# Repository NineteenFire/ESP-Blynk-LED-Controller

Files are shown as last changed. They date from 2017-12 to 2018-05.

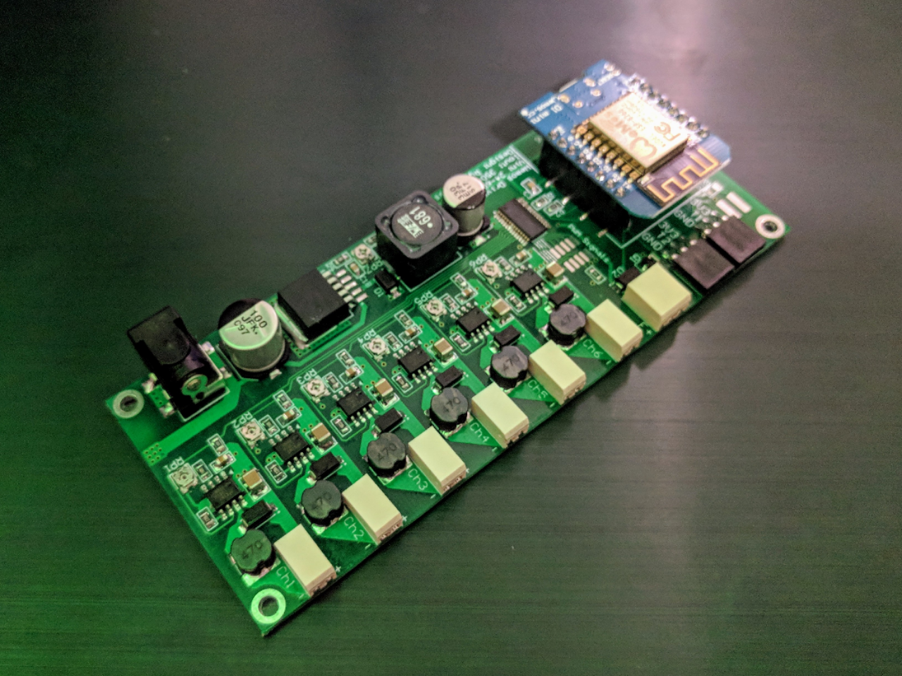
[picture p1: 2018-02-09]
Pictures/Driver PCB.jpg

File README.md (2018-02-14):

# ESP-Blynk-LED-Controller

## Setup after programming ESP:

1. Check your available wifi networks for "LED AP" and connect to it, it should prompt you to select your wifi network and put in your Blynk token (best to copy it to your clipboard before running as there is a 5 minute timeout)
2. Once you've put in that info you should be able to connect via the Blynk app

## Once your Blynk app is connected:

1. Select Sunrise/Sunset, Daylight and Moonlight time period
2. Select "Fan On Temp", this is the temperature setpoint where the fan will be enabled when the heatsink reaches this temperature
3. Select Fade Duration, this is how long the app will take to ramp between light modes (if the ramp overlaps the next start time it will ramp from the current point to the new set values)
4. On setup tab select a test mode, ie "Test MaxPWM" which is your brightest mode
5. Move the sliders to the brightness you want
6. Hit the save button, this will save the current slider values to that mode
7. Repeat steps 4-6 for dim levels and moonlight levels
8. Set mode to normal operation and you should be good to go

## Hardware

### Breadboard wiring diagram:
Breadboard wiring diagram
Parts needed:
- Wemos D1 (or nodeMCU)
- DS18B20
- Adafruit PCA9685
- N-Channel MOSFet to drive fan

### Custom driver PCB
Custom driver PCB

## Libraries

- [Adafruit PWM Servo Driver](https://github.com/adafruit/Adafruit-PWM-Servo-Driver-Library)
- [Arduino JSON](https://arduinojson.org/doc/installation/)
- [Arduino OTA](https://github.com/esp8266/Arduino/tree/master/libraries/ArduinoOTA)
- [Blynk](https://github.com/blynkkk/blynk-library)
- [Dallas Temperature](https://github.com/milesburton/Arduino-Temperature-Control-Library)
- [Simple Timer](https://github.com/marcelloromani/Arduino-SimpleTimer/tree/master/SimpleTimer)
- [Time Library](https://github.com/PaulStoffregen/Time)
- [Wifi Manager](https://github.com/tzapu/WiFiManager)

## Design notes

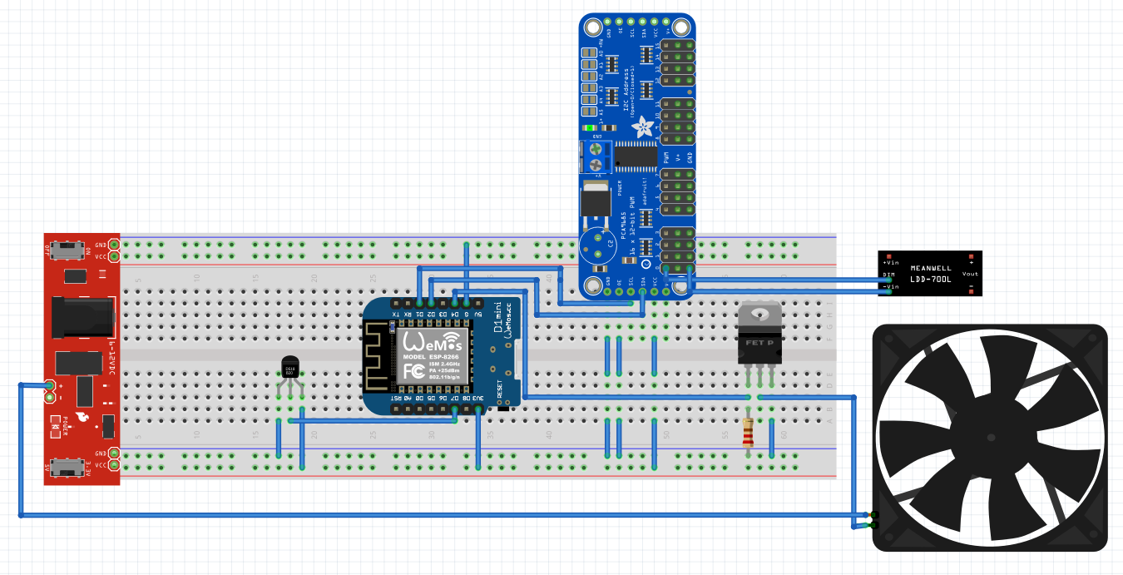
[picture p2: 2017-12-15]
Pictures/Connections.png

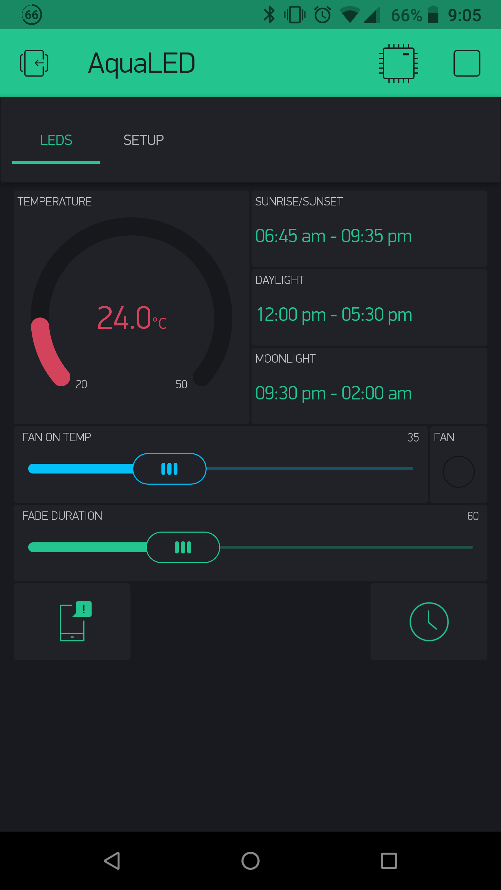
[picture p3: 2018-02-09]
Pictures/Blynk - Main screen.png

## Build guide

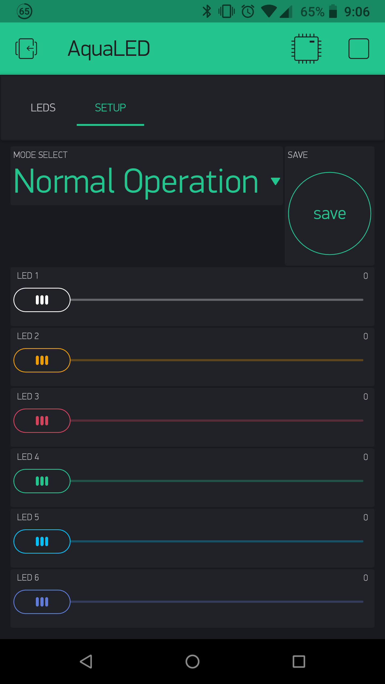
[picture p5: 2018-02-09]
Pictures/Blynk - Setup screen.png

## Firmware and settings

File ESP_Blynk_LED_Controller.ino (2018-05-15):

//#define BLYNK_PRINT Serial    // Comment this out to disable prints and save space

#include <FS.h>                   // https://github.com/tzapu/WiFiManager This Library needs to be included FIRST!
#include <BlynkSimpleEsp8266.h>
#include <ArduinoOTA.h>
#include <TimeLib.h>
#include <WidgetRTC.h>
#include <Wire.h>
#include <Adafruit_PWMServoDriver.h>
#include <OneWire.h> // network library to communicate with the DallasTemperature sensor, 
#include <DallasTemperature.h>  // library for the Temp sensor itself
//included libraries for WiFiManager - AutoConnectWithFSParameters
#include <DNSServer.h>
#include <ESP8266WebServer.h>
#include <WiFiManager.h>          //https://github.com/tzapu/WiFiManager
#include <ArduinoJson.h>          //https://github.com/bblanchon/ArduinoJson
#include <EEPROM.h>

void updateBlynkSliders(boolean updateAll=true);

byte pSDA=4;
byte pSCL=5;
byte pEnFAN=16;
byte pFANPWM=0;
byte pOneWire=13;
byte pOnBoardLED=2;

// WiFiManager
char blynk_token[34] = "BLYNK_TOKEN";//added from WiFiManager - AutoConnectWithFSParameters
//flag for saving data
bool shouldSaveConfig = false;
//callback notifying the need to save config
void saveConfigCallback () {
  BLYNK_LOG("Should save config");
  shouldSaveConfig = true;
}

bool isFirstConnect = true;
bool smartStartupRun = false;
bool appConnected = false;

char Time[16];

unsigned long startsecond = 0;        // time for LEDs to ramp to full brightness
unsigned long stopsecond = 0;         // finish time for LEDs to ramp to dim level from full brightness
unsigned long sunriseSecond = 0;      // time for LEDs to start ramping to dim level
unsigned long sunsetSecond = 0;       // finish time for LEDs to dim off
unsigned long moonStartSecond = 0;      // time for LEDs to start ramping to moonlight level
unsigned long moonStopSecond = 0;       // time for LEDs to ramp off
unsigned long nowseconds = 0;         // time  now  in seconds

//0=not ramping, 3=moon->dim, 4=dim->max, 5=max->dim, 6=dim->moon
unsigned int fadeInProgress = 0;
unsigned long fadeStartTimeMillis = 0;
unsigned long fadeStartTimeSeconds = 0;
unsigned long fadeTimeSeconds = 0;
unsigned long fadeTimeMillis = 0;

struct LEDCh // for storing light intensity values
{
  unsigned int fadeIncrementTime;
  unsigned int currentPWM;
  unsigned int lastPWM;
  unsigned int targetPWM;
  unsigned int maxPWM;
  unsigned int dimPWM;
  unsigned int tempPWM;
  unsigned int moonPWM;
};
typedef struct LEDCh channel;
const int numCh = 6;
channel LEDsettings[numCh];

int LEDMode = 1; //1=operating, 2=Configure MaxPWM, 3=Configure dimPWM, 4=Configure moonPWM

// Data wire is plugged into port 2 on the Wemos
#define ONE_WIRE_BUS D7

// Setup a oneWire instance to communicate with any OneWire devices (not just Maxim/Dallas temperature ICs)
OneWire oneWire(ONE_WIRE_BUS);

// Pass our oneWire reference to Dallas Temperature. 
DallasTemperature sensors(&oneWire);

// array to hold device addresses (can increase array length if using more sensors)
DeviceAddress tempSensors[3];
int numTempSensors;
int fanOnTemp = 0;

WidgetRTC rtc;
WidgetLED fanLED(V14);
BlynkTimer timer;
Adafruit_PWMServoDriver pwm = Adafruit_PWMServoDriver();

void setup()
{
  Wire.begin(pSDA,pSCL);
  //Wire.setClock(400000L);
  ArduinoOTA.begin();
  Serial.begin(115200);
  
  pinMode(pOnBoardLED, OUTPUT);
  pinMode(pFANPWM, OUTPUT);
  pinMode(pEnFAN, OUTPUT);
  digitalWrite(pOnBoardLED, LOW);
  digitalWrite(pFANPWM, LOW);
  digitalWrite(pEnFAN, LOW);
  
  pwm.begin();
  pwm.setPWMFreq(250);

  //Start dallas temperature temp sensors
  sensors.begin();
  // locate devices on the bus
  numTempSensors = sensors.getDeviceCount();
  BLYNK_LOG("Found %d temperature sensors.",numTempSensors);
  for( int i = 0 ; i < numTempSensors ; i++)
  {
    if (!sensors.getAddress(tempSensors[i], i))
    {
      BLYNK_LOG("Unable to find address for Device %d",i);
    }
  }

  //The following code is borrowed from WiFiManager
  //clean FS, for testing
  //SPIFFS.format();

  //read configuration from FS json
  BLYNK_LOG("Mounting FS...");

  if (SPIFFS.begin()) {
    BLYNK_LOG("Mounted file system");
    if (SPIFFS.exists("/config.json")) {
      //file exists, reading and loading
      BLYNK_LOG("Config file exists");
      File configFile = SPIFFS.open("/config.json", "r");
      if (configFile) {
        BLYNK_LOG("Opened config file");
        size_t size = configFile.size();
        // Allocate a buffer to store contents of the file.
        std::unique_ptr<char[]> buf(new char[size]);

        configFile.readBytes(buf.get(), size);
        DynamicJsonBuffer jsonBuffer;
        JsonObject& json = jsonBuffer.parseObject(buf.get());
        json.printTo(Serial);
        if (json.success()) {
          BLYNK_LOG("Parsed json");
          strcpy(blynk_token, json["blynk_token"]);
          BLYNK_LOG("Blynk Token in memory: %s",blynk_token);
        } else {
          BLYNK_LOG("Failed to load json config");
        }
      }
    }else{
      BLYNK_LOG("File config.json does not exist",blynk_token);
    }
  } else {
    BLYNK_LOG("Failed to mount FS");
  }
  //end read
  
  // The extra parameters to be configured (can be either global or just in the setup)
  // After connecting, parameter.getValue() will get you the configured value
  // id/name placeholder/prompt default length
  WiFiManagerParameter custom_blynk_token("blynk", "blynk token", blynk_token, 34);
  
  // WiFiManager
  // Local intialization. Once its business is done, there is no need to keep it around
  WiFiManager wifiManager;

  // Set config save notify callback
  wifiManager.setSaveConfigCallback(saveConfigCallback);

  // Add blynk parameter here
  wifiManager.addParameter(&custom_blynk_token);

  // Reset settings - for testing
  //wifiManager.resetSettings();

  //set minimu quality of signal so it ignores AP's under that quality (default: 8%)
  wifiManager.setMinimumSignalQuality();

  // Sets timeout until configuration portal gets turned off
  // useful to make it all retry or go to sleep
  //wifiManager.setTimeout(120);

  //fetches ssid and pass and tries to connect
  //if it does not connect it starts an access point with the specified name
  //and goes into a blocking loop awaiting configuration
  if (!wifiManager.autoConnect("LED AP")) {
    //Serial.println("failed to connect and hit timeout");
    BLYNK_LOG("Failed to connect and hit timeout");
    delay(3000);
    //reset and try again, or maybe put it to deep sleep
    ESP.reset();
    delay(1000);
  }

  //if you get here you have connected to the WiFi
  BLYNK_LOG("LED Controller connected :)");

  //read updated parameters
  strcpy(blynk_token, custom_blynk_token.getValue());

  //save the custom parameters to FS
  if (shouldSaveConfig) {
    BLYNK_LOG("Saving config");
    DynamicJsonBuffer jsonBuffer;
    JsonObject& json = jsonBuffer.createObject();
    json["blynk_token"] = blynk_token;

    File configFile = SPIFFS.open("/config.json", "w");
    if (!configFile) {
      BLYNK_LOG("failed to open config file for writing");
    }

    json.printTo(Serial);
    json.printTo(configFile);
    configFile.close();
    //end save
  }

  setSyncInterval(1000); //make sure time syncs right away
  Blynk.config(blynk_token);
  while (Blynk.connect() == false)
  {
    // Wait until connected, need to handle case where wifi connects but blynk auth invalid...
    
    if((shouldSaveConfig == false)&&(blynk_token == "BLYNK_TOKEN"))
    {
      //This will erase WiFi settings forcing a new AP where Blynk_token can be entered
      //WiFi.disconnect(true); 
      //ESP.reset();
      //OR
      WiFi.begin("FakeSSID","FakePW");     // Replace current WiFi credentials with fake ones
      delay(1000);
      ESP.restart();
    }
    
  }
  rtc.begin();

  //Can update slider colors here if desired
  //Blynk.setProperty(V0, "color", "#F2FAFF"); // COOL WHITE
  //Blynk.setProperty(V1, "color", "#FFEDE0"); // WARM WHITE
  //Blynk.setProperty(V2, "color", "#FD5635"); // RED
  //Blynk.setProperty(V3, "color", "#BFFFB3"); // LIME
  //Blynk.setProperty(V4, "color", "#2E28FF"); // ROYAL BLUE
  //Blynk.setProperty(V5, "color", "#2ECEFF"); // CYAN
  //Blynk.setProperty(V6, "color", "#FD5635"); // RED
  //Blynk.setProperty(V7, "color", "#BD1313"); // DEEP RED

  //Read LED settings from EEPROM
  if(checkEEPROMPWM() == false)
  {
    //if the EEPROM has not been set previously clear memory
    clearPWMValues();
  }
  readPWMValues();
  
  timer.setInterval(500L, ledFade);           // adjust the led lighting every 500ms
  timer.setInterval(1000L, checkSchedule);    // check every second if fade should start
  timer.setInterval(15000L, checkTemp);       // check heatsink temperature every 15 seconds
  timer.setInterval(60000L, reconnectBlynk);  // check every 60s if still connected to server
  
  digitalWrite(pOnBoardLED, HIGH); //ensure light is OFF
  Blynk.notify("LED Controller ONLINE");
  BLYNK_LOG("End of startup.");
}
void loop()
{
  ArduinoOTA.handle();
  if (Blynk.connected()) {
    Blynk.run();
  }
  timer.run();
}

//===Functions===

void reconnectBlynk() {
  if (!Blynk.connected())
  {
    //Turn onboard LED on to indiciate there is an issue
    digitalWrite(pOnBoardLED, LOW);
    if (Blynk.connect())
    {
      digitalWrite(pOnBoardLED, HIGH);
      BLYNK_LOG("Reconnected");
    }
    else {
      digitalWrite(pOnBoardLED, LOW);
      BLYNK_LOG("Not reconnected");
    }
  }else
  {
    //Turn onboard LED off
    digitalWrite(pOnBoardLED, HIGH);
    clockDisplay();
  }
}

void checkSchedule()        // check if ramping should start
{
  if (year() != 1970) 
  {
    nowseconds = ((hour() * 3600) + (minute() * 60) + second());
    //nowseconds = elapsedSecsToday(now());
    unsigned long timingInfo = startsecond + sunriseSecond + moonStartSecond + fadeTimeSeconds;
    if((smartStartupRun == false)&&(timingInfo != 0))
    {
      smartLEDStartup();
      smartStartupRun = true;
      setSyncInterval(600000); //set time sync to every 10 minutes
    }
  }else
  {
    nowseconds = 86401; //set seconds out of range to avoid un-wanted ramps
  }
  
  int i;
  int difference;
  if((nowseconds == sunriseSecond)&&(fadeInProgress != 4)) //ramp from 0 to sunrise values
  {
    sprintf(Time, "%02d:%02d:%02d", hour() , minute(), second());
    BLYNK_LOG("%s\tStarting sunrise...",Time);
    
    fadeInProgress = 4;
    fadeStartTimeMillis = millis();
    fadeStartTimeSeconds = now();
    for(i = 0; i < numCh; i = i + 1) {
      LEDsettings[i].targetPWM = LEDsettings[i].dimPWM;
      LEDsettings[i].lastPWM = LEDsettings[i].currentPWM;
      if(LEDsettings[i].targetPWM > LEDsettings[i].lastPWM){difference = (LEDsettings[i].targetPWM - LEDsettings[i].lastPWM);}
      if(LEDsettings[i].targetPWM < LEDsettings[i].lastPWM){difference = (LEDsettings[i].lastPWM - LEDsettings[i].targetPWM);}
      LEDsettings[i].fadeIncrementTime = fadeTimeMillis / difference;
    }
  }
  else if((nowseconds == startsecond)&&(fadeInProgress != 5)) //ramp from sunrise to max 
  {
    sprintf(Time, "%02d:%02d:%02d", hour() , minute(), second());
    BLYNK_LOG("%s\tRamping to full brightness...",Time);
    
    fadeInProgress = 5;
    fadeStartTimeMillis = millis();
    fadeStartTimeSeconds = now();
    for (i = 0; i < numCh; i = i + 1) {
      LEDsettings[i].targetPWM = LEDsettings[i].maxPWM;
      LEDsettings[i].lastPWM = LEDsettings[i].currentPWM;
      if(LEDsettings[i].targetPWM > LEDsettings[i].lastPWM){difference = (LEDsettings[i].targetPWM - LEDsettings[i].lastPWM);}
      if(LEDsettings[i].targetPWM < LEDsettings[i].lastPWM){difference = (LEDsettings[i].lastPWM - LEDsettings[i].targetPWM);}
      LEDsettings[i].fadeIncrementTime = fadeTimeMillis / difference;
    }
  }
  else if((nowseconds == stopsecond)&&(fadeInProgress != 6)) //ramp from max to sunset values
  {
    sprintf(Time, "%02d:%02d:%02d", hour() , minute(), second());
    BLYNK_LOG("%s\tStarting sunset...",Time);
    
    fadeInProgress = 6;
    fadeStartTimeMillis = millis();
    fadeStartTimeSeconds = now();
    for (i = 0; i < numCh; i = i + 1) {
      LEDsettings[i].targetPWM = LEDsettings[i].dimPWM;
      LEDsettings[i].lastPWM = LEDsettings[i].currentPWM;
      if(LEDsettings[i].targetPWM > LEDsettings[i].lastPWM){difference = (LEDsettings[i].targetPWM - LEDsettings[i].lastPWM);}
      if(LEDsettings[i].targetPWM < LEDsettings[i].lastPWM){difference = (LEDsettings[i].lastPWM - LEDsettings[i].targetPWM);}
      LEDsettings[i].fadeIncrementTime = fadeTimeMillis / difference;
    }
  }
  else if((nowseconds == sunsetSecond)&&(fadeInProgress != 7)) //ramp from sunset to off
  {
    sprintf(Time, "%02d:%02d:%02d", hour() , minute(), second());
    BLYNK_LOG("%s\tRamping LEDs off...",Time);
    
    fadeInProgress = 7;
    fadeStartTimeMillis = millis();
    fadeStartTimeSeconds = now();
    for (i = 0; i < numCh; i = i + 1) {
      LEDsettings[i].targetPWM = 0;
      LEDsettings[i].lastPWM = LEDsettings[i].currentPWM;
      if(LEDsettings[i].targetPWM > LEDsettings[i].lastPWM){difference = (LEDsettings[i].targetPWM - LEDsettings[i].lastPWM);}
      if(LEDsettings[i].targetPWM < LEDsettings[i].lastPWM){difference = (LEDsettings[i].lastPWM - LEDsettings[i].targetPWM);}
      LEDsettings[i].fadeIncrementTime = fadeTimeMillis / difference;
    }
  }
  else if((nowseconds == moonStartSecond)&&(fadeInProgress != 8)) //ramp from off to moon
  {
    sprintf(Time, "%02d:%02d:%02d", hour() , minute(), second());
    BLYNK_LOG("%s\tRamping LEDs to moonlight...",Time);
    
    fadeInProgress = 8;
    fadeStartTimeMillis = millis();
    fadeStartTimeSeconds = now();
    for (i = 0; i < numCh; i = i + 1) {
      LEDsettings[i].targetPWM = LEDsettings[i].moonPWM;
      LEDsettings[i].lastPWM = LEDsettings[i].currentPWM;
      if(LEDsettings[i].targetPWM > LEDsettings[i].lastPWM){difference = (LEDsettings[i].targetPWM - LEDsettings[i].lastPWM);}
      if(LEDsettings[i].targetPWM < LEDsettings[i].lastPWM){difference = (LEDsettings[i].lastPWM - LEDsettings[i].targetPWM);}
      LEDsettings[i].fadeIncrementTime = fadeTimeMillis / difference;
    }
  }
  else if((nowseconds == moonStopSecond)&&(fadeInProgress != 9)) //ramp off from moon
  {
    sprintf(Time, "%02d:%02d:%02d", hour() , minute(), second());
    BLYNK_LOG("%s\tRamping LEDs to moonlight...",Time);
    
    fadeInProgress = 9;
    fadeStartTimeMillis = millis();
    fadeStartTimeSeconds = now();
    for (i = 0; i < numCh; i = i + 1) {
      LEDsettings[i].targetPWM = 0;
      LEDsettings[i].lastPWM = LEDsettings[i].currentPWM;
      if(LEDsettings[i].targetPWM > LEDsettings[i].lastPWM){difference = (LEDsettings[i].targetPWM - LEDsettings[i].lastPWM);}
      if(LEDsettings[i].targetPWM < LEDsettings[i].lastPWM){difference = (LEDsettings[i].lastPWM - LEDsettings[i].targetPWM);}
      LEDsettings[i].fadeIncrementTime = fadeTimeMillis / difference;
    }
  }
  if(appConnected)
  {
    //if we're in normal mode and ramping keep the sliders updated
    if((LEDMode == 1)&&(fadeInProgress != 0))
    {
      //only update one slider per second to reduce traffic
      updateBlynkSliders(false);
    }
  }
}

void ledFade()
{
  int i;
  if(fadeInProgress != 0)
  {
    unsigned long timeElapsed = millis() - fadeStartTimeMillis; //time since the start of fade
    for (i = 0; i < numCh; i = i + 1)
    {
      if(LEDsettings[i].currentPWM != LEDsettings[i].targetPWM)
      {
        //if adjustments are necessary
        if(LEDsettings[i].lastPWM < LEDsettings[i].targetPWM)
        {
          //value increasing
          LEDsettings[i].currentPWM = LEDsettings[i].lastPWM + (timeElapsed / LEDsettings[i].fadeIncrementTime);
        }
        if(LEDsettings[i].lastPWM > LEDsettings[i].targetPWM)
        {
          //value decreasing
          LEDsettings[i].currentPWM = LEDsettings[i].lastPWM - (timeElapsed / LEDsettings[i].fadeIncrementTime);
        }
        //if target == last set to target
        if(LEDsettings[i].lastPWM == LEDsettings[i].targetPWM)
        {
          LEDsettings[i].currentPWM = LEDsettings[i].targetPWM;
        }
      }
      LEDsettings[i].currentPWM = constrain(LEDsettings[i].currentPWM,0,4095);
    }
    if(now() > (fadeStartTimeSeconds + fadeTimeSeconds))
    {
      fadeInProgress = 0;
      for (i = 0; i < numCh; i = i + 1) {
        LEDsettings[i].currentPWM = LEDsettings[i].targetPWM;
      }
    }
    if(LEDMode==1)
    {
      writeLEDs();
    }
  }
}

void writeLEDs() {
  int i;
  for (i = 0; i < numCh; i = i + 1) {
    pwm.setPWM(i,0,LEDsettings[i].currentPWM);
  }
}

void checkTemp()
{
  //read all sensors and keep track of maximum temperature
  sensors.requestTemperatures();
  float temperature[numTempSensors];
  float maxTemperature = 0.0;
  int i = 0;
  for(i = 0 ; i < numTempSensors ; i++)
  {
    temperature[i] = sensors.getTempC(tempSensors[i]);
    if(temperature[i] > maxTemperature)maxTemperature=temperature[i];
  }
  
  //write the maximum temperature to Blynk
  Blynk.virtualWrite(V20, maxTemperature);
  
  //if higher than fan set temperature then turn fan on
  int intTemp = maxTemperature; //temp as integer
  if(intTemp > fanOnTemp)
  {
    //Calculate PWM by temp over fanOnTemp, at 0C above run at 10%, 20C above 100%
    int fanPWM = intTemp - fanOnTemp;
    fanPWM = constrain(fanPWM,0,20);
    fanPWM = map(fanPWM,0,20,10,1023);
    analogWrite(pFANPWM,fanPWM);
    //turn fan on
    digitalWrite(pEnFAN,HIGH);
    fanLED.on();
  }
  if(intTemp < (fanOnTemp-2))
  {
    //turn fan off
    digitalWrite(pEnFAN,LOW);
    analogWrite(pFANPWM,0);
    fanLED.off();
  }
}
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

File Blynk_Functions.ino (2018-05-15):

// This function will run every time Blynk connection is established
BLYNK_CONNECTED() 
{
  if (isFirstConnect)
  {
    Blynk.syncVirtual(V12);//check fade time before schedule
    Blynk.syncVirtual(V10,V11,V13,V22); //Read start/stop/sunrise/sunset times, fan on temp
    Blynk.virtualWrite(V15,1);
    isFirstConnect = false;
    Blynk.run();
  }
}
// This is called when Smartphone App is opened
BLYNK_APP_CONNECTED() {
  BLYNK_LOG("App Connected");
  appConnected = true;
  if(LEDMode == 1)updateBlynkSliders();
}
// This is called when Smartphone App is closed
BLYNK_APP_DISCONNECTED() {
  BLYNK_LOG("App Disconnected");
  appConnected = false;
}
BLYNK_WRITE(V0) {// slider widget to set the maximum led level from the Blynk App.
  int value;// = param.asInt();
  float valueF = param.asFloat();
  valueF = valueF * 40.95;
  value = valueF;
  value = constrain(value,0,4095);
  //if in mode 1 or 2 take new value as currentPWM and set LED to that value for viewing purposes
  if((LEDMode == 2)||(LEDMode == 3)||(LEDMode == 4))
  {
    LEDsettings[0].tempPWM = value;
    pwm.setPWM(0, 0, LEDsettings[0].tempPWM);
    BLYNK_LOG("Setting ch1 current to %d",LEDsettings[0].tempPWM);
  }
}
BLYNK_WRITE(V1) {// slider widget to set the maximum led level from the Blynk App.
  int value;
  float valueF = param.asFloat();
  valueF = valueF * 40.95;
  value = valueF;
  value = constrain(value,0,4095);
  if((LEDMode == 2)||(LEDMode == 3)||(LEDMode == 4))
  {
    LEDsettings[1].tempPWM = value;
    pwm.setPWM(1, 0, LEDsettings[1].tempPWM);
    BLYNK_LOG("Setting ch2 current to %d",LEDsettings[1].tempPWM);
  }
}
BLYNK_WRITE(V2) {// slider widget to set the maximum led level from the Blynk App.
  int value;
  float valueF = param.asFloat();
  valueF = valueF * 40.95;
  value = valueF;
  value = constrain(value,0,4095);
  if((LEDMode == 2)||(LEDMode == 3)||(LEDMode == 4))
  {
    LEDsettings[2].tempPWM = value;
    pwm.setPWM(2, 0, LEDsettings[2].tempPWM);
    BLYNK_LOG("Setting ch3 current to %d",LEDsettings[2].tempPWM);
  }
}
BLYNK_WRITE(V3) {// slider widget to set the maximum led level from the Blynk App.
  int value;
  float valueF = param.asFloat();
  valueF = valueF * 40.95;
  value = valueF;
  value = constrain(value,0,4095);
  if((LEDMode == 2)||(LEDMode == 3)||(LEDMode == 4))
  {
    LEDsettings[3].tempPWM = value;
    pwm.setPWM(3, 0, LEDsettings[3].tempPWM);
    BLYNK_LOG("Setting ch4 current to %d",LEDsettings[3].tempPWM);
  }
}
BLYNK_WRITE(V4) {// slider widget to set the maximum led level from the Blynk App.
  int value;
  float valueF = param.asFloat();
  valueF = valueF * 40.95;
  value = valueF;
  value = constrain(value,0,4095);
  if((LEDMode == 2)||(LEDMode == 3)||(LEDMode == 4))
  {
    LEDsettings[4].tempPWM = value;
    pwm.setPWM(4, 0, LEDsettings[4].tempPWM);
    BLYNK_LOG("Setting ch5 current to %d",LEDsettings[4].tempPWM);
  }
}
BLYNK_WRITE(V5) {// slider widget to set the maximum led level from the Blynk App.
  int value;
  float valueF = param.asFloat();
  valueF = valueF * 40.95;
  value = valueF;
  value = constrain(value,0,4095);
  if((LEDMode == 2)||(LEDMode == 3)||(LEDMode == 4))
  {
    LEDsettings[5].tempPWM = value;
    pwm.setPWM(5, 0, LEDsettings[5].tempPWM);
    BLYNK_LOG("Setting ch6 current to %d",LEDsettings[5].tempPWM);
  }
}
BLYNK_WRITE(V10) //Blynk pin for sunrise/sunset time (time LEDs start turning on / hit moon values)
{
  TimeInputParam t(param);

  if (t.hasStartTime())
  {
    sunriseSecond = (t.getStartHour() * 3600) + (t.getStartMinute() * 60);
  }else
  {
    //if start time is not set assume 8AM
    sunriseSecond = 28800;
  }
  if (t.hasStopTime())
  {
    sunsetSecond = ((t.getStopHour() * 3600) + (t.getStopMinute() * 60) - fadeTimeSeconds + 86400) % 86400;
  }else
  {
    //if stop time is not set assume 8PM
    sunsetSecond = 72000 - fadeTimeSeconds;
  }

  sprintf(Time, "%02d:%02d:%02d", sunriseSecond/3600 , (sunriseSecond / 60) % 60, 0);
  BLYNK_LOG("Sunrise time is: %s",Time);
  sprintf(Time, "%02d:%02d:%02d", sunsetSecond/3600 , (sunsetSecond / 60) % 60, 0);
  BLYNK_LOG("Sunset time is: %s",Time);
}
BLYNK_WRITE(V11) //Blynk pin for daylight start/stop time
{
  TimeInputParam t(param);
  
  if (t.hasStartTime())
  {
    startsecond = (t.getStartHour() * 3600) + (t.getStartMinute() * 60);
  }else
  {
    //if start time is not set assume noon
    startsecond = 43200;
  }
  if (t.hasStopTime())
  {
    stopsecond = ((t.getStopHour() * 3600) + (t.getStopMinute() * 60) - fadeTimeSeconds + 86400) % 86400;
  }else
  {
    //if stop time is not set assume 4PM
    stopsecond = 57600 - fadeTimeSeconds;
  }
  
  sprintf(Time, "%02d:%02d:%02d", startsecond/3600 , ((startsecond / 60) % 60), 0);
  BLYNK_LOG("Daylight start time is: %s",Time);
  sprintf(Time, "%02d:%02d:%02d", stopsecond/3600 , ((stopsecond / 60) % 60), 0);
  BLYNK_LOG("Daylight stop time is: %s",Time);
}
BLYNK_WRITE(V12) // slider widget to set the led fade duration up tp 3 hours.
{
  int value = param.asInt();
  fadeTimeSeconds = map(value, 0, 180, 60, 10800);      // 1 minute fade duration is minimum
  fadeTimeMillis  = map(value, 0, 180, 60000, 10800000);// 3 hour fade duration is maximum

  BLYNK_LOG("Fade Time in seconds: %d",fadeTimeSeconds);
}
BLYNK_WRITE(V13) //Blynk pin for moonlight time
{
  TimeInputParam t(param);

  if (t.hasStartTime())
  {
    moonStartSecond = (t.getStartHour() * 3600) + (t.getStartMinute() * 60);
  }else
  {
    //if start time is not set assume 11PM
    moonStartSecond = 82800;
  }
  if (t.hasStopTime())
  {
    moonStopSecond = ((t.getStopHour() * 3600) + (t.getStopMinute() * 60) - fadeTimeSeconds + 86400) % 86400;
  }else
  {
    //if stop time is not set assume 2AM
    moonStopSecond = (86400 + 7200 - fadeTimeSeconds) % 86400;
  }

  sprintf(Time, "%02d:%02d:%02d", moonStartSecond/3600 , (moonStartSecond / 60) % 60, 0);
  BLYNK_LOG("Moonlight start time is: %s",Time);
  sprintf(Time, "%02d:%02d:%02d", moonStopSecond/3600 , (moonStopSecond / 60) % 60, 0);
  BLYNK_LOG("Moonlight stop time is: %s",Time);
}
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

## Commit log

2017-12-04 Update ESP_Blynk_LED_Controller.ino
    Changed DS18B20 code to use array to allow more than 2 sensors to be connected, maximum value is send to Blynk app and used for turning fan on/off
2017-12-09 Update ESP_Blynk_LED_Controller.ino
    Fixed issues with time syncing at startup
    [ESP_Blynk_LED_Controller.ino]
2017-12-11 Update ESP_Blynk_LED_Controller.ino
    Updated fan enable pin to GPIO16 (D0) to avoid conflict with on-board LED which is being used to signal when controller is not connected to Blynk or starting up.
    [ESP_Blynk_LED_Controller.ino]
2018-02-07 Update Blynk_Functions.ino
    updated pwm writes to use setPWM instead of setPin
2018-05-15 Update EEPROM.ino
    Updated serial prints to Blynk logs to reduce serial traffic when not debugging
2018-05-15 Update Blynk_Functions.ino
    Corrected some text strings in Blynk Logs, ie don't need to add new line command since it's done automatically
    [Blynk_Functions.ino]
2018-05-15 Update ESP_Blynk_LED_Controller.ino
    Updated remaining serial prints to Blynk logs, removed simple timer (functionality is in Blynk library), simplified repeated code in smartLEDStartup routine.
